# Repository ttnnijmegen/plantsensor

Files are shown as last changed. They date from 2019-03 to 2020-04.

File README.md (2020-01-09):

# plantsensor
indoor plant soil moisture sensor with temperature and humidity.
PCB based on HiGrow rev0.1 and RFM95
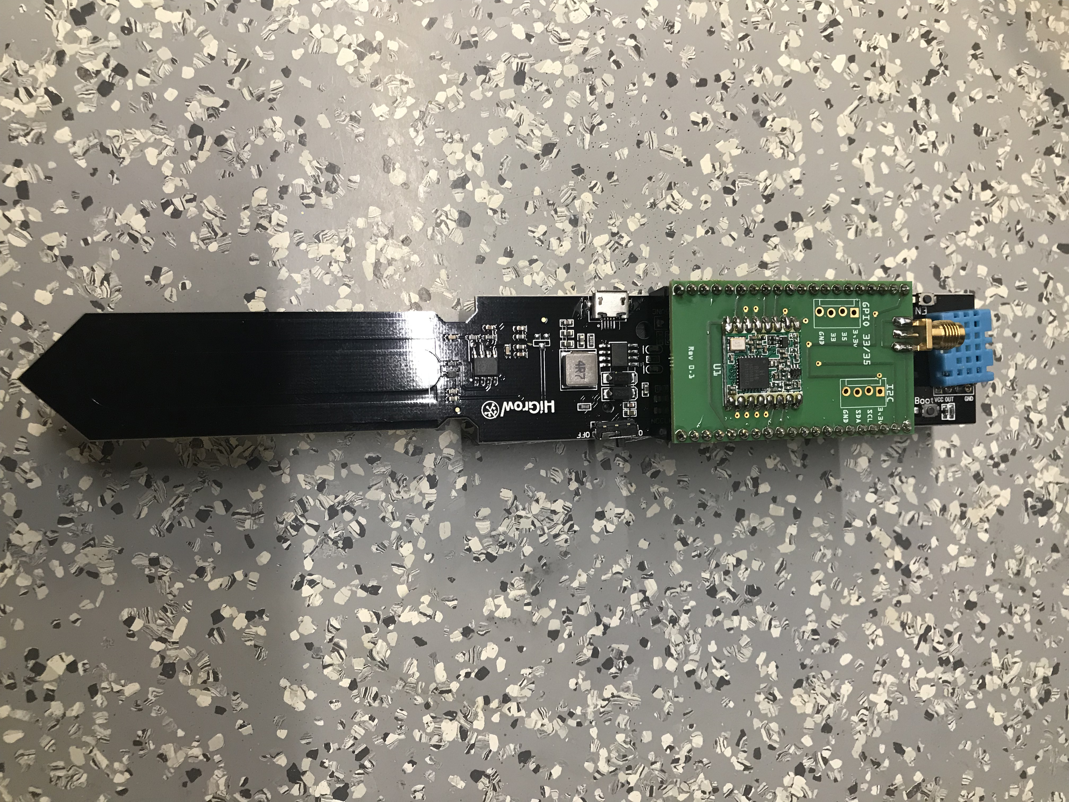
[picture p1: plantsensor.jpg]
plantsensor


Update: In the mean time there is a new product on the market. 
Apartently also with a LoRaWAN shield:
https://github.com/Xinyuan-LilyGO/TTGO-HiGrow
https://github.com/Xinyuan-LilyGO/LilyGO-T-HiGrow-LoRaWLAN

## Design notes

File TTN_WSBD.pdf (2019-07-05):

Workshop:
“Aan de slag met sensoren”

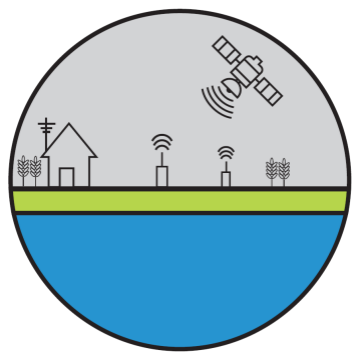
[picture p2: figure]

Workshop:
“Aan de slag met sensoren”

Amteburger kalibratie van
satellietbeelden met crowedsourced sensoren aangesloten op een crowedsourced netwerk

WIFI:
SSID: WSBD-Gast
WW: waterbeheer

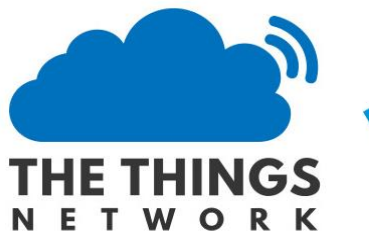
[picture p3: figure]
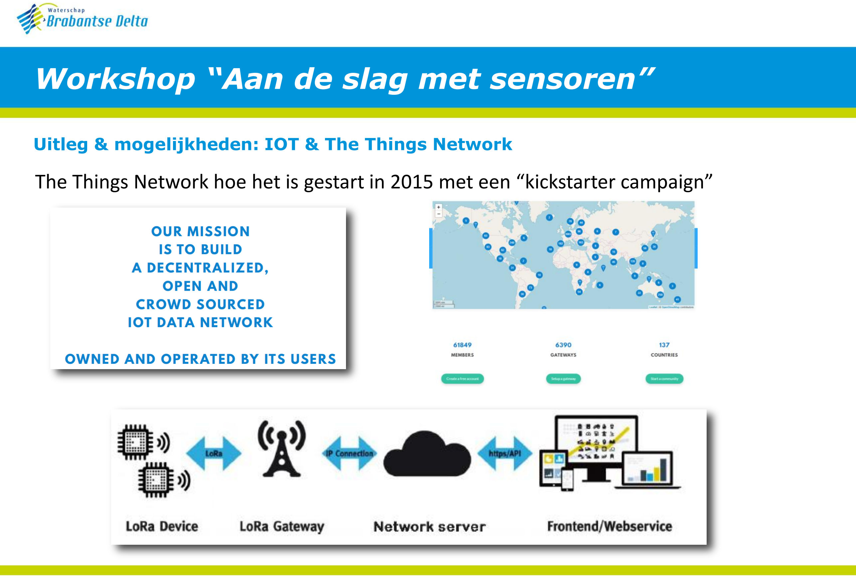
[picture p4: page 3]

Workshop “Aan de slag met sensoren”

Uitleg & mogelijkheden: IOT & The Things Network
The Things Network hoe het is gestart in 2015 met een “kickstarter campaign”

Workshop “Aan de slag met sensoren”

Uitleg & mogelijkheden: IOT & The Things Network
The Things Network hoe het is gestart in 2015 met een “kickstarter campaign”

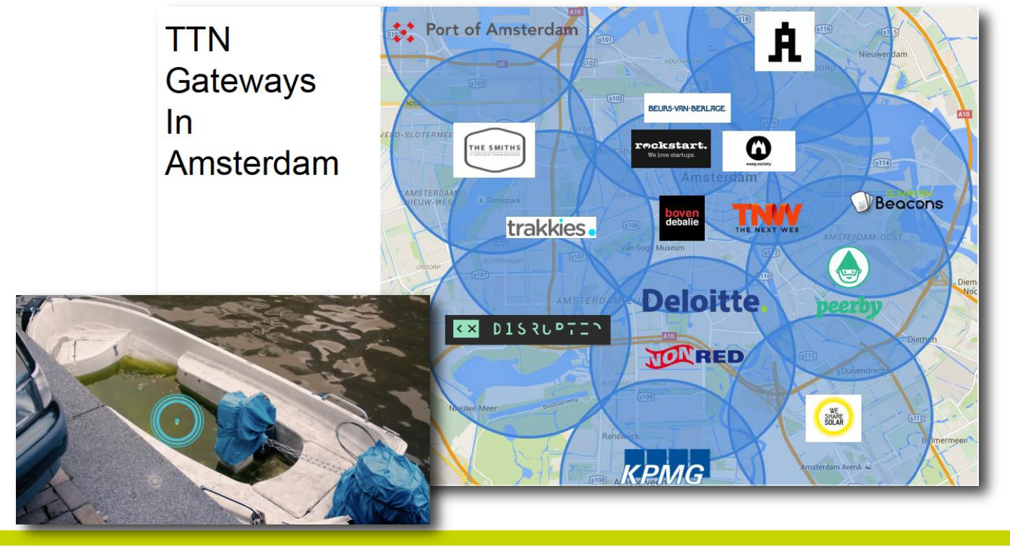
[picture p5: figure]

Workshop “Aan de slag met sensoren”

Uitleg & mogelijkheden: IOT & The Things Network

Internet of things

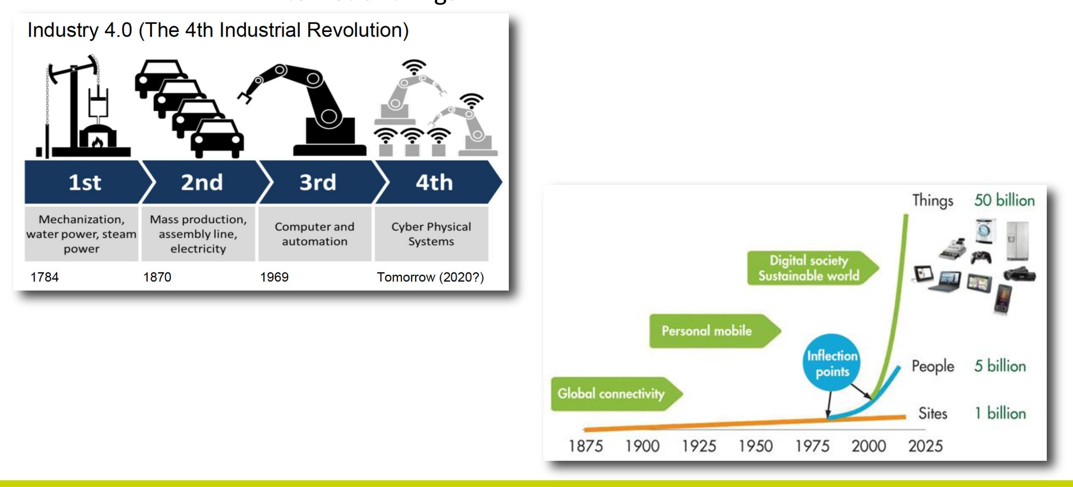
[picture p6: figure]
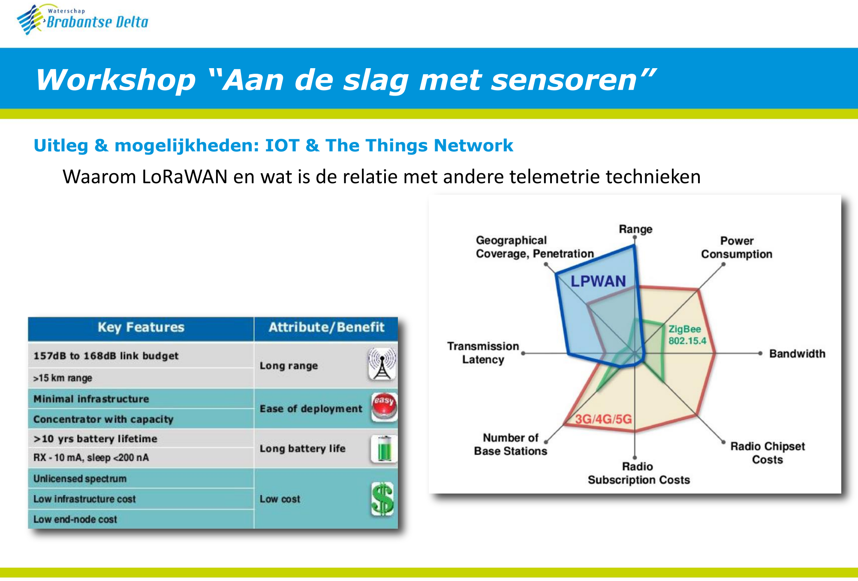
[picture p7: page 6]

Workshop “Aan de slag met sensoren”

Uitleg & mogelijkheden: IOT & The Things Network
Waarom LoRaWAN en wat is de relatie met andere telemetrie technieken

Workshop “Aan de slag met sensoren”

Uitleg & mogelijkheden: IOT & The Things Network
Waarom LoRaWAN en wat is de relatie met andere telemetrie technieken

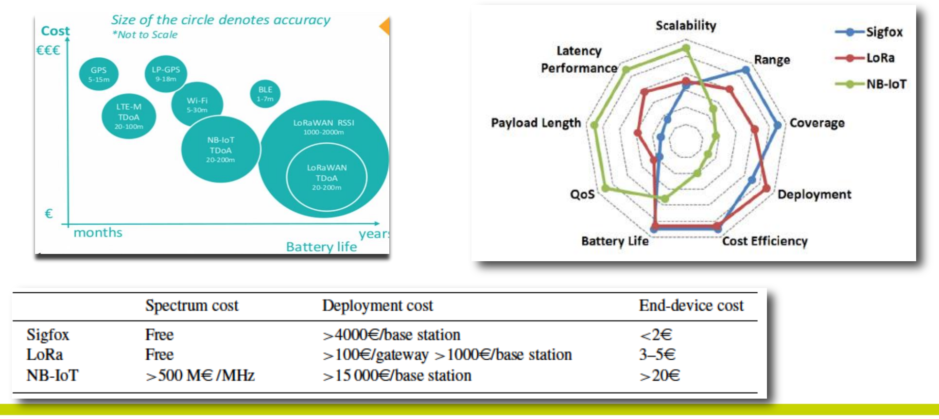
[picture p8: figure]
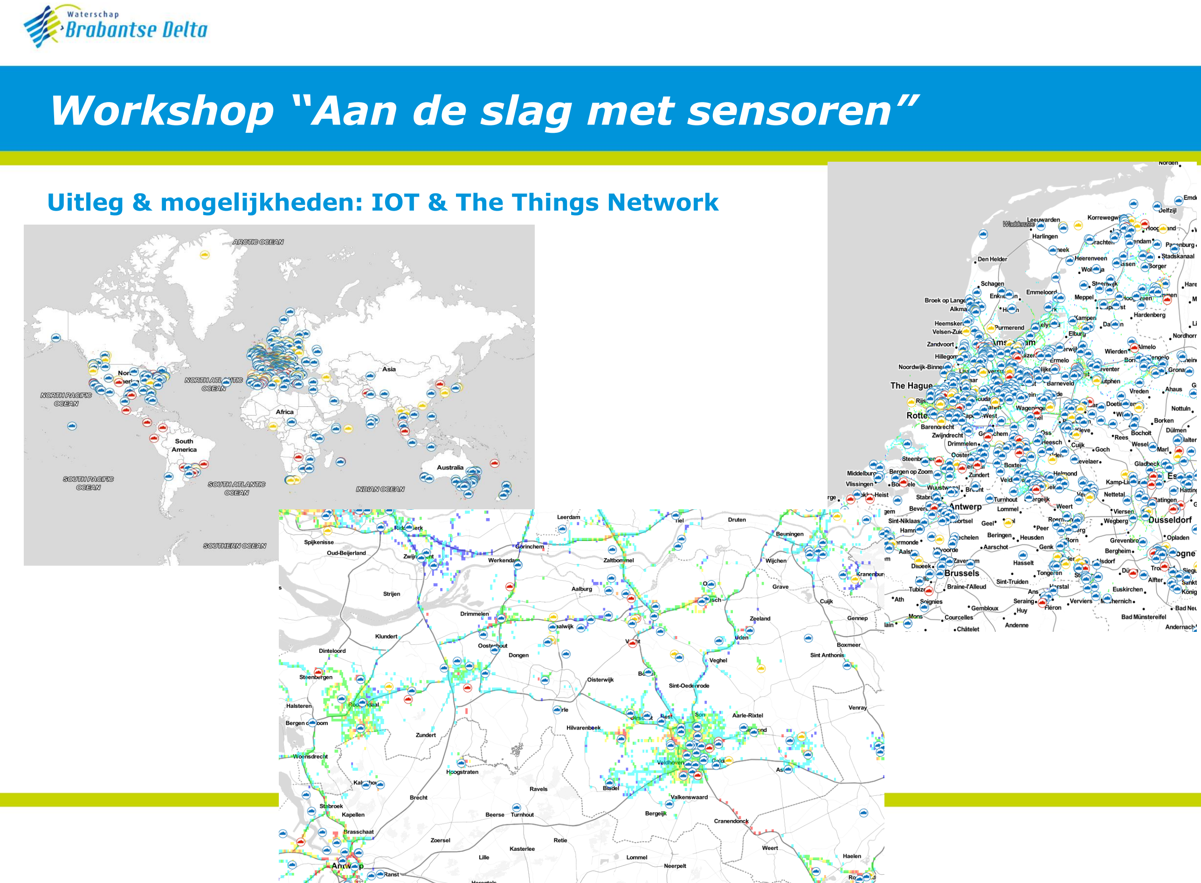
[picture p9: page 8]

Workshop “Aan de slag met sensoren”

Uitleg & mogelijkheden: IOT & The Things Network

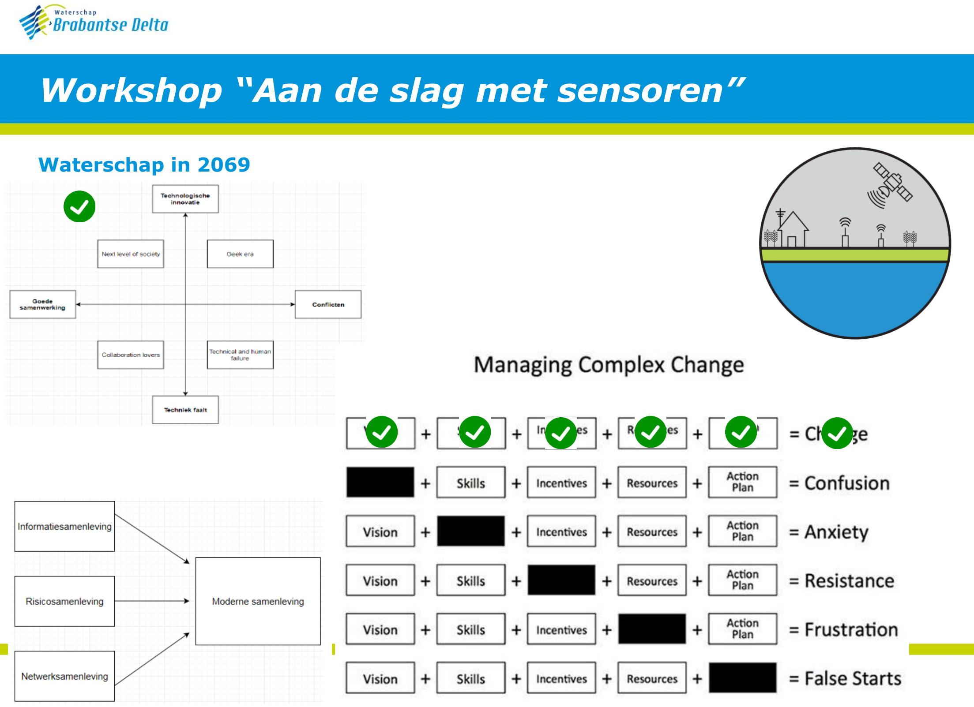
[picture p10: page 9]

Workshop “Aan de slag met sensoren”

Waterschap in 2069

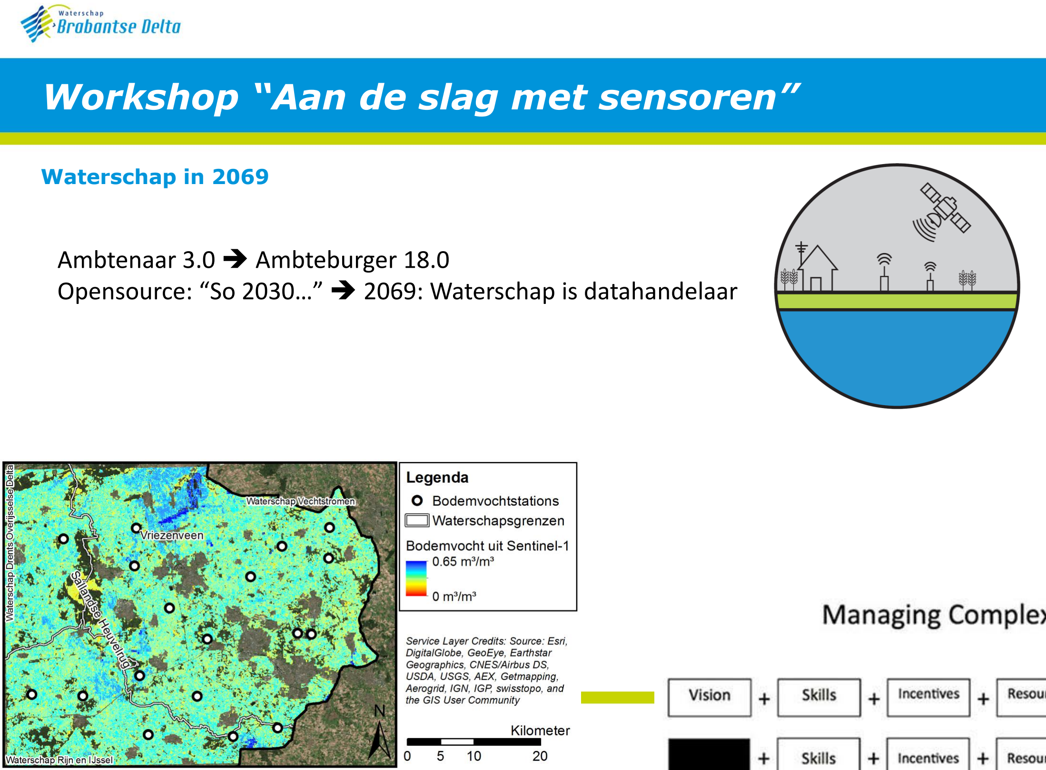
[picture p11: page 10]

Workshop “Aan de slag met sensoren”

Waterschap in 2069

Ambtenaar 3.0 → Ambteburger 18.0
Opensource: “So 2030…” → 2069: Waterschap is datahandelaar

Workshop “Aan de slag met sensoren”

Workshop intro

Hier nog plaatjes invoegen: Trello
Sensor
PCB
Casing

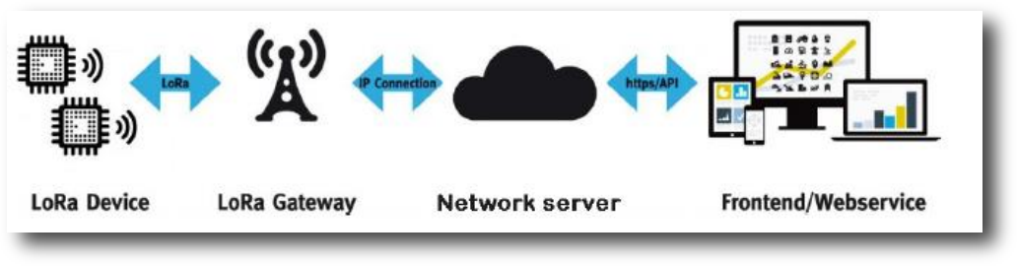
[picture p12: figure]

Workshop “Aan de slag met sensoren”

Inhoud

- 13:30-14:00
- Uitleg & mogelijkheden:
- IOT & The Things Network (mogelijkheden voor het waterschap)
- Waterschap 2069
- Workshop intro
- 14:00-15:00
- Workshop “Aan de slag met sensoren”
- 15:00-15:15
- Afsluiting – inspirerende ideeën

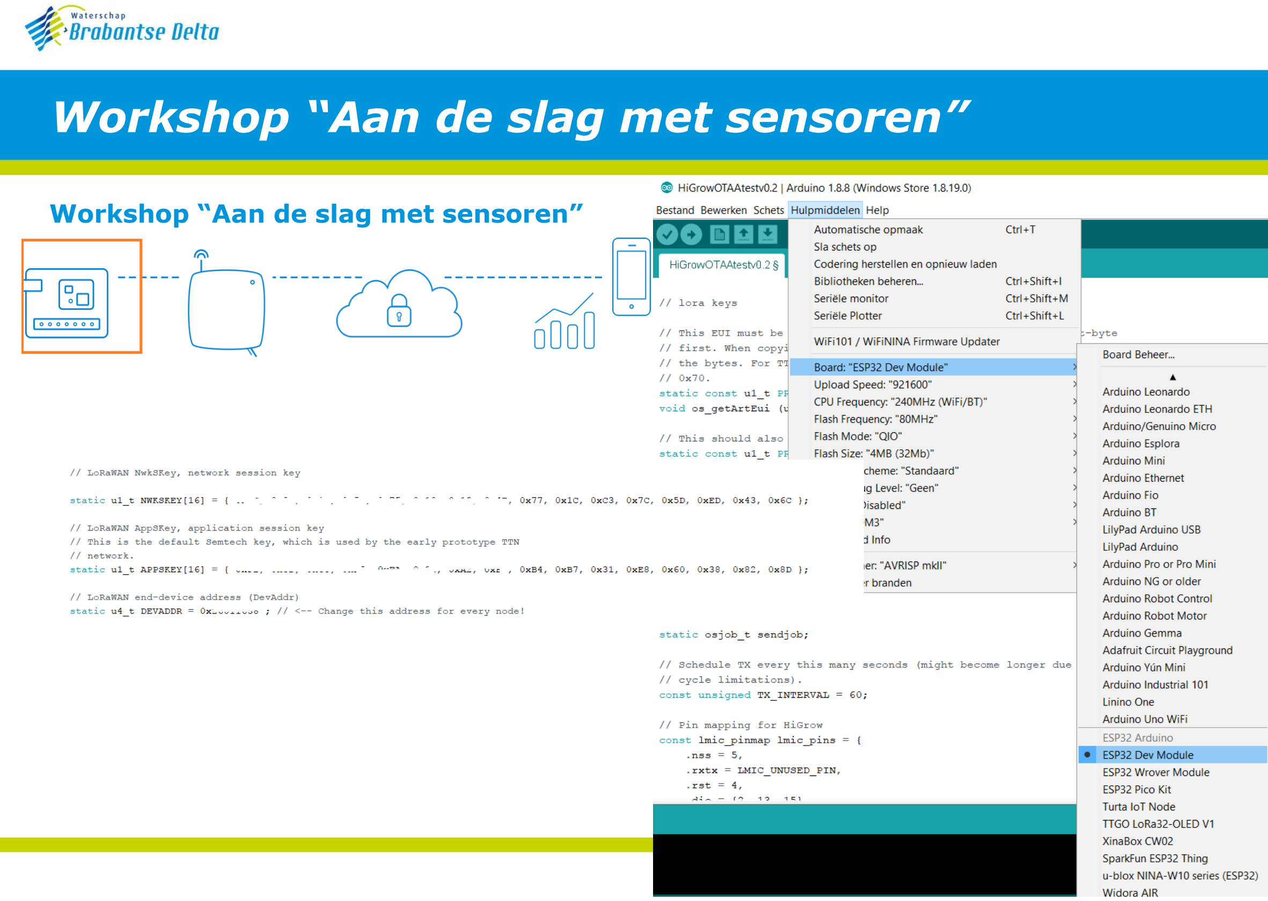
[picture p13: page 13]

Workshop “Aan de slag met sensoren”

Workshop “Aan de slag met sensoren”

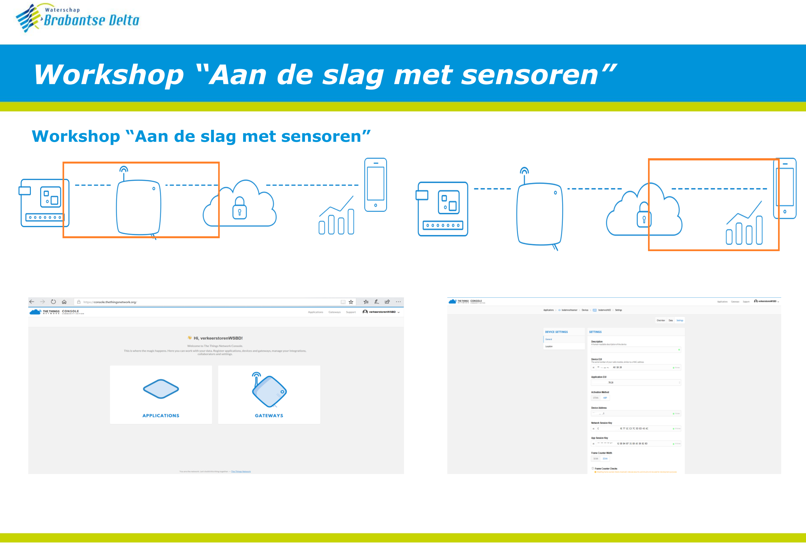
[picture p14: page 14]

Workshop “Aan de slag met sensoren”

Workshop “Aan de slag met sensoren”

Workshop “Aan de slag met sensoren”

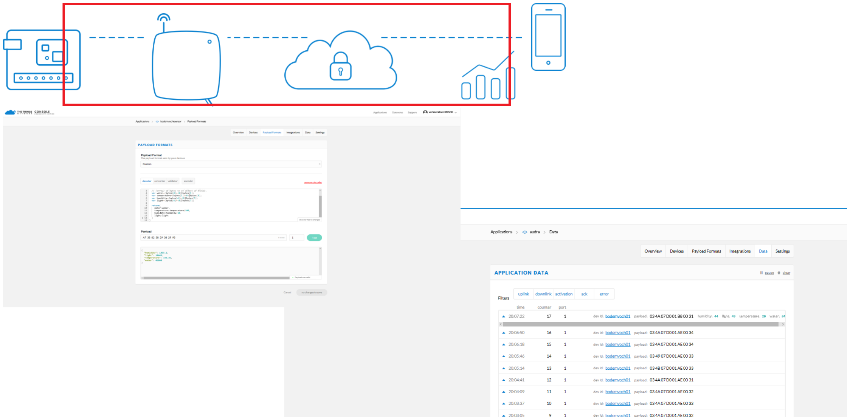
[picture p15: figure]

Workshop “Aan de slag met sensoren”

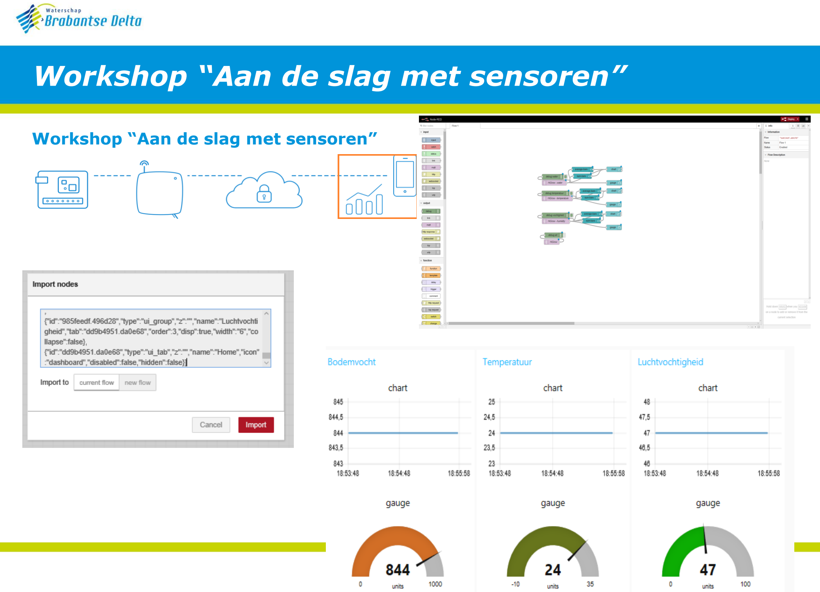
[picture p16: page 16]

Workshop “Aan de slag met sensoren”

Workshop “Aan de slag met sensoren”

Workshop “Aan de slag met sensoren”

Workshop “Aan de slag met sensoren”

Wellicht nog “nice to have” invoegen voor COLLOS

Workshop “Aan de slag met sensoren”

Inhoud

- 13:30-14:00
- Uitleg & mogelijkheden:
- IOT & The Things Network (mogelijkheden voor het waterschap)
- Waterschap 2069
- Workshop intro
- 14:00-15:00
- Workshop “Aan de slag met sensoren”
- 15:00-15:15
- Afsluiting – inspirerende ideeën

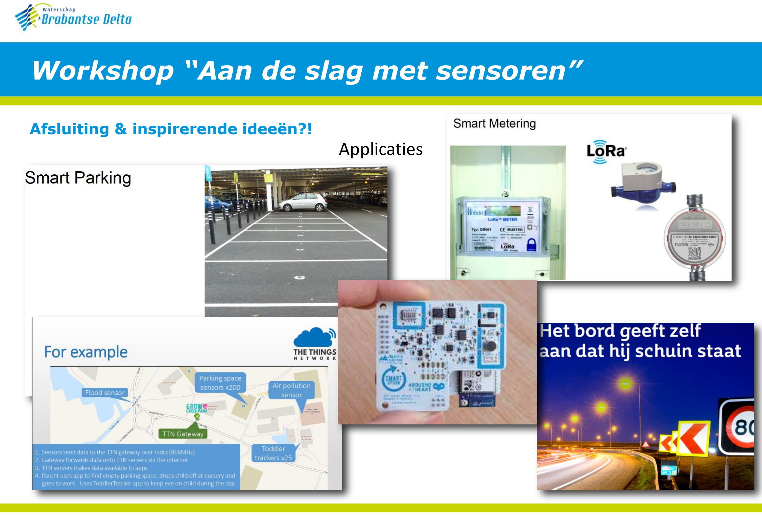
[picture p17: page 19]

Workshop “Aan de slag met sensoren”

Afsluiting & inspirerende ideeën?!
Applicaties

Workshop “Aan de slag met sensoren”

Credits

- Presentatie & ontwerp: | Roger & Wouter
- Ontwerp PCB: | Mark & Roger
- Code & debug: | Rob & Roger
- Installatie voorbereiding: Toine & Roger
- Infograph: | Mariozee
- Casing?: | Mark?
- Testers: | Wouter, Mark, Jarno, Linda, Rob,
| Audra , XXX

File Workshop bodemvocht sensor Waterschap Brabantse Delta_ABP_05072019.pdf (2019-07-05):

# Workshop bodemvocht sensor Waterschap Brabantse Delta v0.4_ABP

Dit is de uitgebreide handleiding ten behoeve van de workshop voor het maken van een sensor met een dashboard voor Waterschap Brabantse Delta. Hierbij wordt een microcontroller met diverse sensoren om de omgeving af te tasten aangesloten op “The Things Network” om middels LoRaWAN zend technologie gegevens te verzenden naar een eind applicatie. Dat is in deze workshop een node-red dashboard dat lokaal op de pc draait. De stappen die doorlopen worden betreffen de gehele architectuur van “The Things Network”. Onderstaande afbeelding visualiseert dit in een architectuur overzicht:

Dit overzicht zal ieder keer terug komen bij de relevante stappen in het proces van sensor naar eind applicatie. De stappen zijn onderstaand weergegeven in het overzicht van de inhoud.

## Inhoud

Data storage | Fout! Bladwijzer niet gedefinieerd.
IFTTT channel | Fout! Bladwijzer niet gedefinieerd.

## DEVICE: Opzet sensor

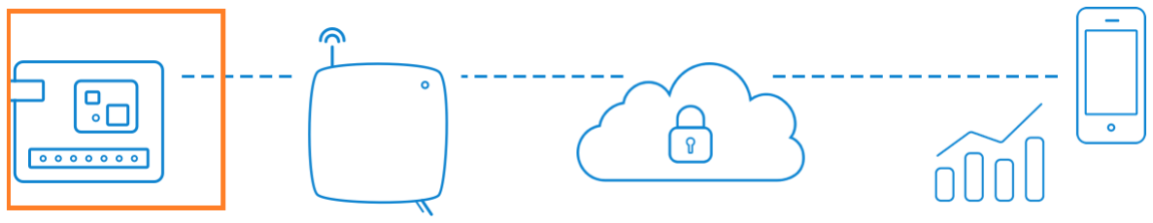
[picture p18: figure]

Allereerst dient het “device” te worden klaargemaakt om gegevens uit te lezen uit de sensoren die het heeft en deze in het juiste formaat door te zenden. Ieder “device” is uniek en bij dit “device” maken we gebruik van een microprocessor genaamd ESP32.

### Installatie arduino:

Download de arduino IDE (Integrated Development Environment) en installeer deze op uw computer.

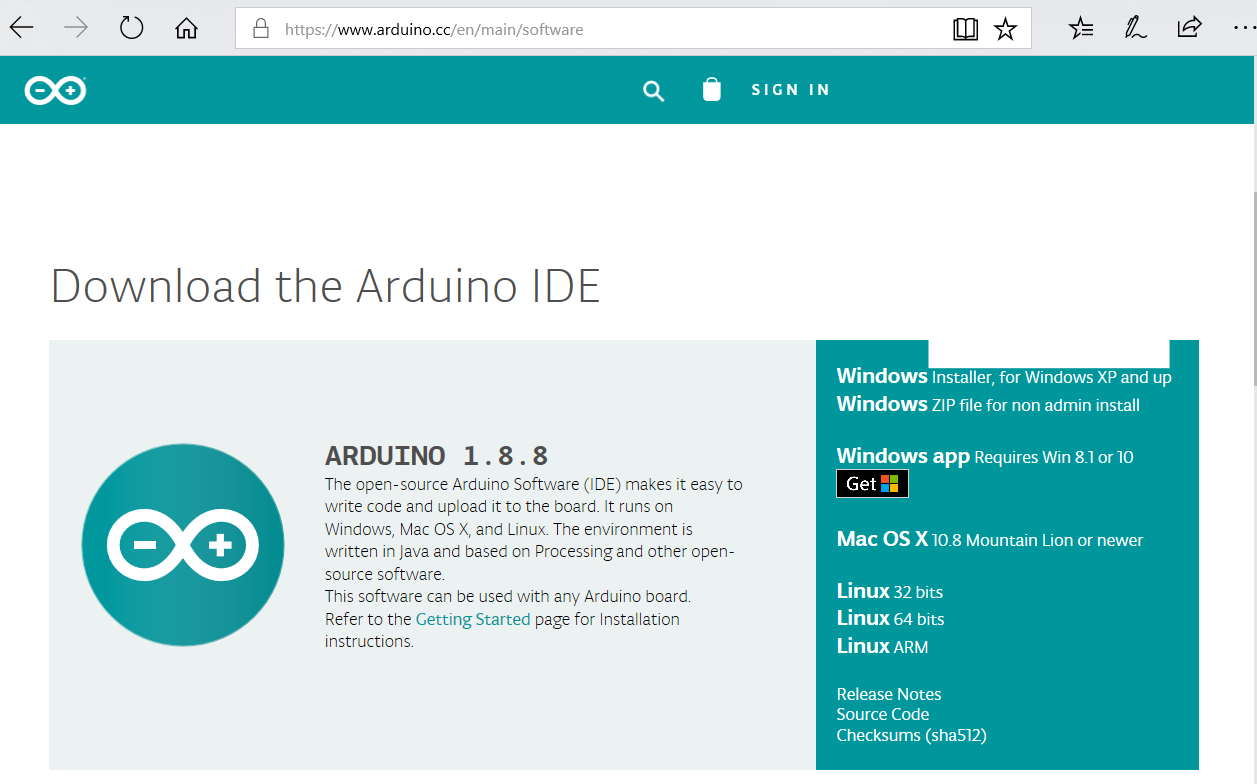
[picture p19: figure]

### Installatie ESP32 voor arduino

Om bepaalde type borden te kunnen gebruiken met de arduino IDE dienen deze te worden geïnstalleerd. Een uitgebreidere tutorial hierover voor de ESP32 is te vinden op de onderstaande link.

https://randomnerdtutorials.com/installing-the-esp32-board-in-arduino-ide-windows-instructions/

Kort samengevat komt het erop neer dat u bij voorkeuren de onderstaande link dient toe te voegen:

https://dl.espressif.com/dl/package_esp32_index.json

Ga vervolgens naar boardbeheer:

En installeer de ESP 32 borden:

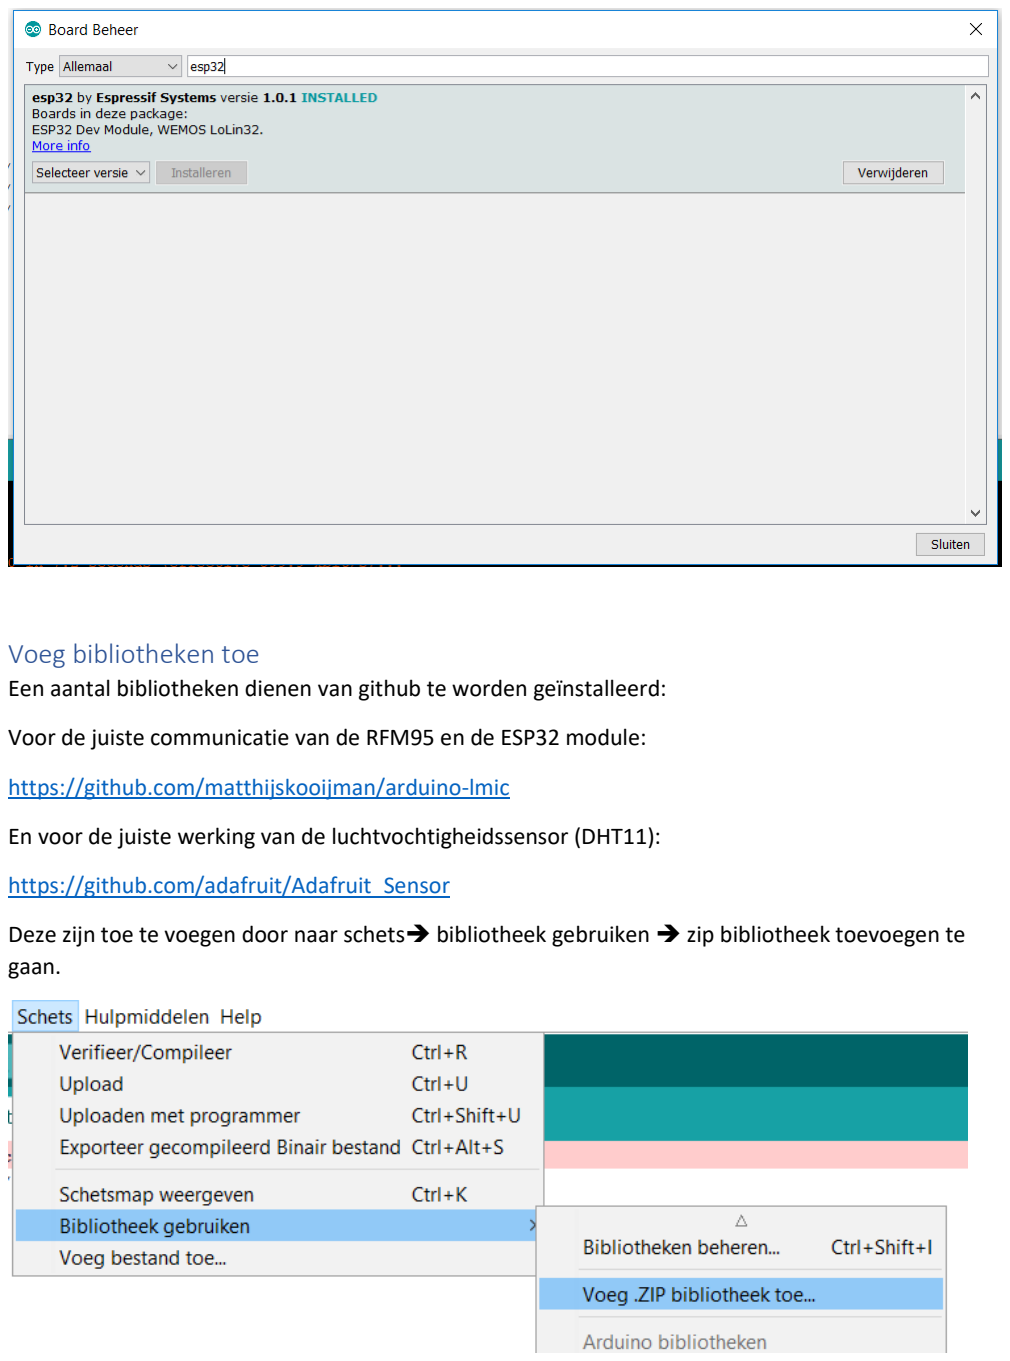
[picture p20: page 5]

### Voeg bibliotheken toe

Een aantal bibliotheken dienen van github te worden geïnstalleerd:

Voor de juiste communicatie van de RFM95 en de ESP32 module:

https://github.com/matthijskooijman/arduino-lmic

En voor de juiste werking van de luchtvochtigheidssensor (DHT11):

https://github.com/adafruit/Adafruit_Sensor

Deze zijn toe te voegen door naar schets→ bibliotheek gebruiken → zip bibliotheek toevoegen te gaan.

Daarnaast kunnen bibliotheken via de arduino IDE worden toegevoegd.

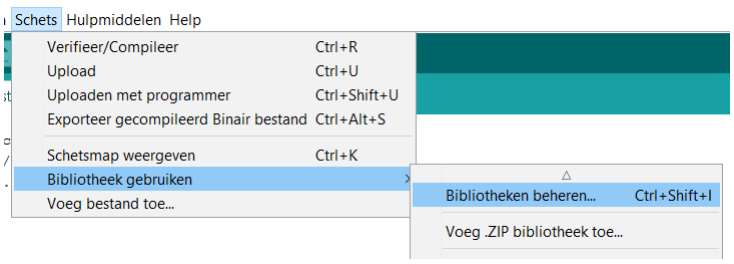
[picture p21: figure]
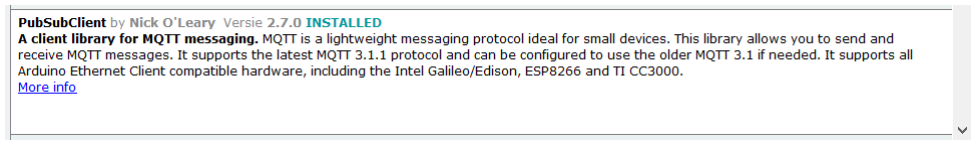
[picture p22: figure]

## CLOUD: Aanmaken van The Things Network account

Om gegevens te kunnen versturen, via de gateway, naar de cloud van “The things network” dient er een “The Things Network” account aangemaakt te worden.

Ga naar www.thethingsnetwork.org en “Sign up”.

Geef je credentials op en je zult een email ontvangen ten behoeve van verificatie van je email.

Log vervolgens in op: https://account.thethingsnetwork.org/users/login

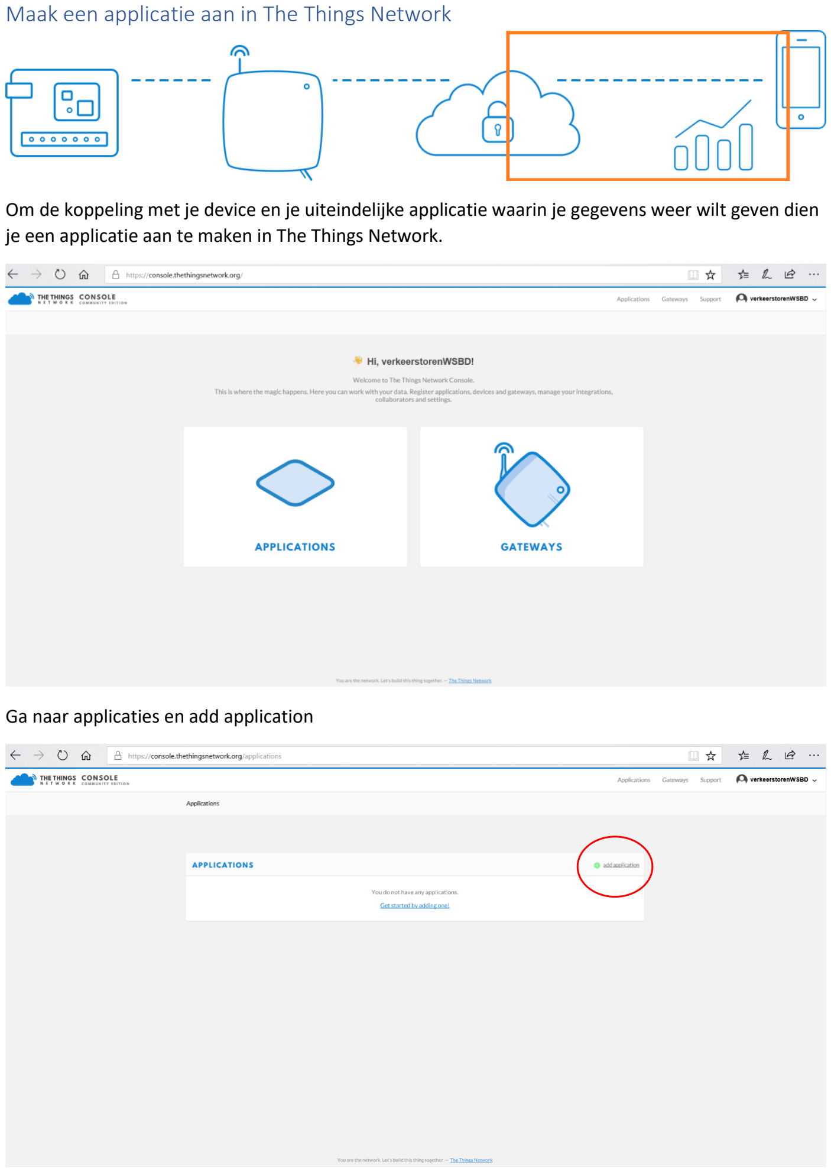
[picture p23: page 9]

### Maak een applicatie aan in The Things Network

Om de koppeling met je device en je uiteindelijke applicatie waarin je gegevens weer wilt geven dien je een applicatie aan te maken in The Things Network.

Ga naar applicaties en add application

Geef een applicatie ID op (in kleine letters zonder rare tekens) En “add application” (bijvoorbeeld bodemvochtsensor). Deze naam is uniek voor het gehele “The Things Network”.

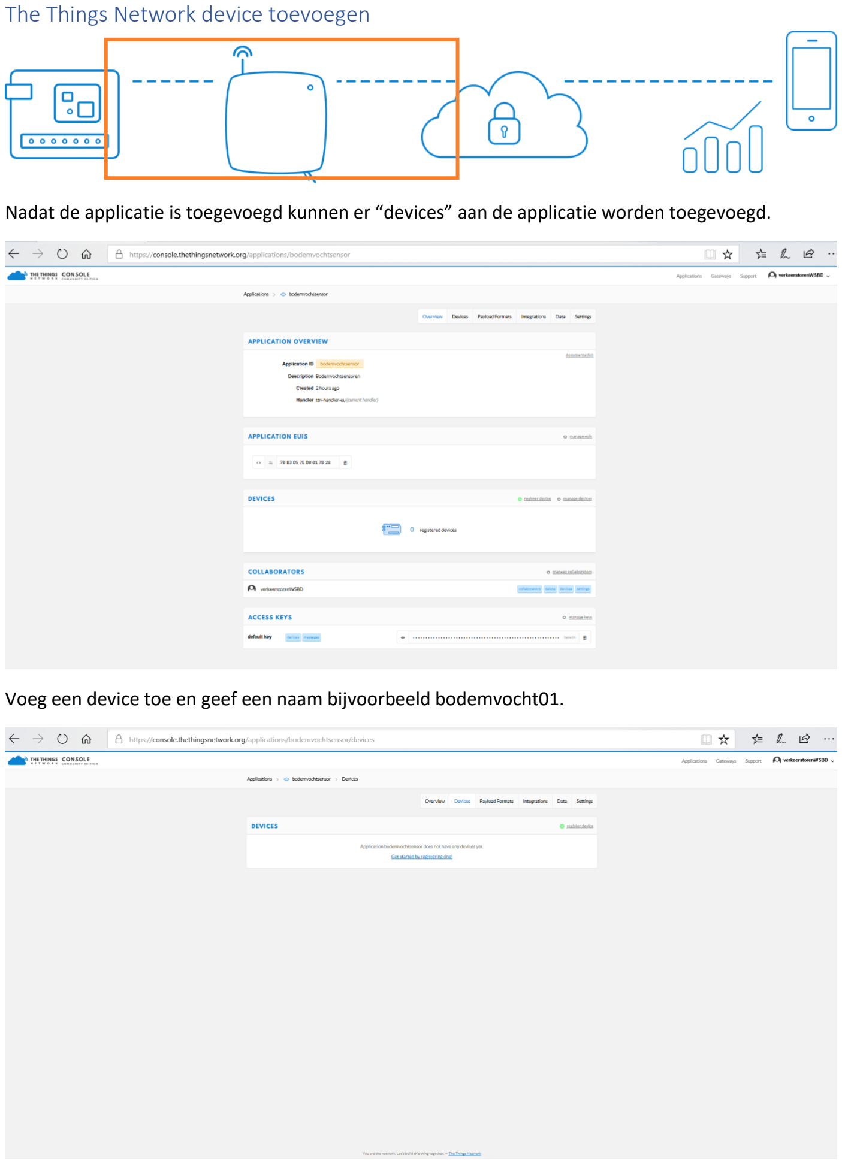
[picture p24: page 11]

### The Things Network device toevoegen

Nadat de applicatie is toegevoegd kunnen er “devices” aan de applicatie worden toegevoegd.

Voeg een device toe en geef een naam bijvoorbeeld bodemvocht01.

Laat Device EUI leeg om automatisch ingevuld te laten worden.

Druk bij device eui op de gekruisde pijltjes zodat device eui wordt gecreeerd

Je gaat nu terug naar het console en krijgt details van het net geregistreerde device te zien.

### ABP voorbeeld instellen in The Things Network

Ga naar settings en zet het device activation method op ABP in plaats van op OTAA. Zet daarnaast de framecounter check uit.

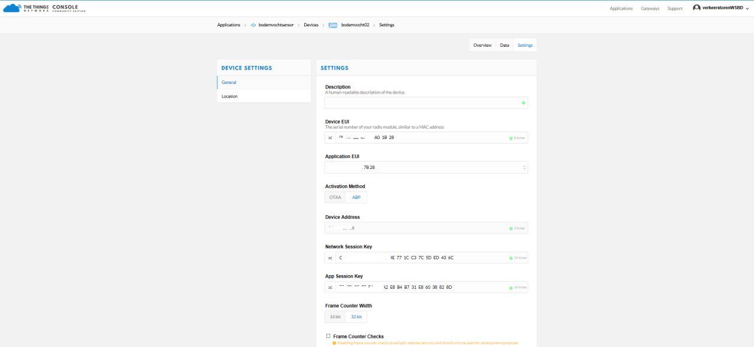
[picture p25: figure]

Zet framecounter check uit en klik vervolgens op de knop ‘save’.

### Arduino LoRa ABP sketch

De code voor de arduino sketch staat op:

https://github.com/ttnnijmegen/plantsensor/tree/master/src

Vul de sleutels in die bij de ABP device settings staan in the things network bij overview. Klik daarbij voor networksession key en app session key op <> zodat de sleutels in MSB formaat verschijnen.

Vul het device adress in achter 0x

De sketch is nu bijna klaar om te uploaden.

Na het invullen van de LoRA keys kan de sketch worden geverifieerd waarbij de code wordt gecompileerd en gecheckt op consistentie en aansluiting op het juiste board. Dit gebeurd met het vinkje. (bord is ESPDEV module)

Als dit allemaal goed is gegaan dient de com poort gecheckt te worden als het apparaat aan is gesloten op de USB poort:

Nu kan de sketch worden ge-upload naar het bord. Dit gebeurd met het pijltje naar rechts.

Bij het verbinden dient op de reset knop te worden gedrukt zodat de sketch naar het board kan uploaden. (connecting)


### Payload encryption


Om de juiste waarden in de applicatie te kunnen tonen dienen de bytes die worden verstuurd door de “device vertaald te worden in wat meer menselijke taal. Hiervoor is de payload functie. Ook worden gegevens hiermee versleuteld zodat alleen de gebruiker weet wat voor informatie het “device “ verstuurd. De decoder functie is toe te voegen door naar het payload format te gaan op de application pagina. Hier kan worden gekozen voor custom payload zoals in de ino file staat beschreven. Er kan ook worden gekozen voor het cayenne LPP formaat. Ook hiervoor dient de ino file te worden aangepast.

Knip en plak de payload decoder (in je applicatie bij payload formats) deze staat als tekst in het ino bestand op github:

https://github.com/ttnnijmegen/plantsensor/tree/master/src


selecteer het payload formaat dat correspondeerd met de ino file. Dus kopieer de tekst uit het ino bestand en selecteer custom om vervolgens deze tekst te plakken of selecteer het LPP formaat.

En test de functie met de volgende payload en druk op save

40 D1 1B 12 68 00 B0 00 01 DD C1 F2 E2 82 F2 03 97 7C 9F 49 B9

In het tabblad data zie je nu waarden in plaats van hex waarden verschijnen

## APPLICATION: Applicatie set-up

### Node-red dashboard installatie


Voor dit type dashboard is de custom payload optie vereist.

Node-red is een soort ETL (extract transfer load) tool voor diverse toepassingen. In deze workshop maken we gebruik van node-red om een simpel dashboard te maken van de data die “The things network” verstuurd middels MQTT.

Installatie van Node-red:

https://nodered.org/docs/getting-started/installation

Installeer eerst Node-js


Ga vervolgens verder met node-red door de volgende code in het opdrachtprompt te zetten (zoek CMD)

npm install -g --unsafe-perm node-red

Na een succesvolle installatie kan in het command prompt “node-red” worden ingevoerd en zo start node-red:


### Node-red gebruik

Nadat node-red in het command prompt is ingevoerd kan de node-red server worden benaderd op het adres dat door de server in het command prompt wordt opgegeven.

Dit is het lokale adres (127.0.0.1) met de poort 1880

Als dit ingevoerd is in een willekeurige internet browser start het gebruikersscherm van node-red:

Aan de linker kant staan diverse nodes die te gebruiken zijn aan de rechterkant het control panel en in het midden is “where the magic happens”…

Door naar de drie horizontale streepjes rechts boven te gaan opent een menu. Hier kun je “manage pallete” kiezen en op deze manier nieuwe nodes installeren.


Je ziet welke nodes er al zijn geïnstalleerd. En door op het tablad install te klikken kun je additionele nodes installeren.

Binnen deze workshop maken we gebruik van een Node-red dashboard en hiervoor dienen een aantal dashboard nodes geïnstalleerd te zijn. Namelijk:

*average-bars

*sum-bars

En “node-red-dashboard”


Nadat deze zijn geinstalleerd kan het voorontworpen dashboard worden geïmporteerd door simpelweg de code uit het “node-red.txt” document te kopieerden en te plakken.

De flows zijn nu te zien met de “dashboard nodes”

De opbouw van het dashboard is te zien als op de grafiek knop aan de rechterkant wordt gedrukt:

Door op het pijltje met het vierkantje te drukken wordt het scherm geopend waarop het dashboard wordt weergegeven.


Om het dashboard te voeden met waarden van de sensor dienen de juiste sleutels van de applicatie te worden ingevoerd in het dashboard.

Open een van de paarse nodes (MQTT nodes)

Vervang waar nu bodemvochtsensor staat door je eigen application ID en vervang bodemvocht02 door je eigen Device ID.


Klik daarna op het pennetje naast “eu.thethings.network:1883”. Druk op tabblad security

De gebruiksnaam vertaald zich in application ID

Het wachtwoord betreffen de acces keys van de applicatie

Klik op done in node red en op deploy om de applicatie te verversen

In het debug window (knopje met het lieve heersbeestje) zie je de waarden binnenkomen die de (groene) debug nodes ontvangen:


Wat uiteindelijk resulteert in waarden in het dashboard.

### Cayenne-COLLOS dashboard

Voor implementatie van Cayenne met het COLLOS dashboard dienen in de ino file te vinden op

https://github.com/ttnnijmegen/plantsensor/tree/master/src

de juiste regels te zijn gecommend en uncommend. Daarnaast dient bij de applications pagina het payload format “cayenne LPP” te zijn geselecteerd.


Bij de applications pagina, integrations voeg de cayenne integratie toe:

Vul daarbij een process ID in naar keuze:

Bij access keys selecteer de default keys.

Voeg ook de integratie “COLLOS” toe. Dit staat voor collaboration location services. Hiermee kan de locatie van de node bepaald worden.

Kies voor Process ID vul rssi in, bij access keys de default keys.

Bij url vul: https://api.preview.collos.org/semtech-localization-algorithms/v1/rssi

Method is POST, Cayenne channel is 20.

Voor de COLLOS subscription keys vul de sleutels in die je bij COLLOS hebt gekregen of apart hebt ontvangen.


Indien goed ingevuld zou de locatie van de device in overview zichtbaar moeten worden:

Er kan nu ook een dashboard worden gecreëerd op cayenne.


Door naar MyDevicesCayenne (https://cayenne.mydevices.com/?_ga=2.65099950.1099267064.1552320718-1638656246.1552320718) te gaan kunt u inloggen of een account aanmaken.

Na inloggen kan er een nieuw device worden aangemaakt:

Selecteer daarbij eerst bij LoraWAN, The things network:

En kies vervolgens het Cayenne protocol door cayenne in de zoekbalk in te typen;

Door de juiste device id in te voeren worden alle kanalen waarop de sensor waarden verzend vanzelf zichtbaar in het dashboard:

## Meer cloud functionaliteiten


### Collaboration

Het is mogelijk collaborators toe te voegen aan je applicatie. Hierdoor kun je samenwerken met elkaar en de data die binnenkomt van de sensoren in de applicatie met elkaar delen.

### COLLOS

ref: https://www.thethingsnetwork.org/docs/applications/collos/quick-start.html

This guide walks you through applying for Collos membership, subscribing to the APIs and configuring the Collos integration in The Things Network Console.

- Apply for a Collos membership: http://preview.collos.org/Home/Apply
- When your membership has been approved, sign in to the Collos portal
- Go to Products
- Click Semtech LoRaWAN Localization
- Click Subscribe to subscribe to the APIs
- Getting your subscription key
- Once your subscription has been approved, you can find your Collos subscription key.
- Sign in to the Collos portal
- Click on your name in the top right
- Click Profile
- Click Show to show your Collos subscription keys

- You can use both Primary key and Secondary key for the Collos integration.
- Configuring the integration
- Sign in to The Things Network Console
- Under Applications, go to your application
- Go to Integrations
- Click add integration
- Enter a Process ID, for example rssi or tdoa
- Select an Access Key. This key should have at least the devices rights to update the location in the device registry
- In URL, enter one of the Collos API endpoints:
- LoRa TDOA + WiFi: Copy https://api.preview.collos.org/localization-lora-recipes/v1/loraWifi
- LoRa TDOA: Copy https://api.preview.collos.org/semtech-localization-algorithms/v1/tdoa
- LoRa RSSI: Copy https://api.preview.collos.org/semtech-localization-algorithms/v1/rssi
- Enter your Collos subscription key
- Enter the Cayenne channel. If provided, the integration will send the location of your devices to myDevices Cayenne as GPS on the specified channel
- Click Add integration
- To compare results from the different algorithms, you can add multiple integration processes for the three algorithms available and use different Cayenne channels.


🎉 You have now successfully configured the Collos integration. You will now see your device moving in The Things Network Console as well as in myDevices Cayenne.

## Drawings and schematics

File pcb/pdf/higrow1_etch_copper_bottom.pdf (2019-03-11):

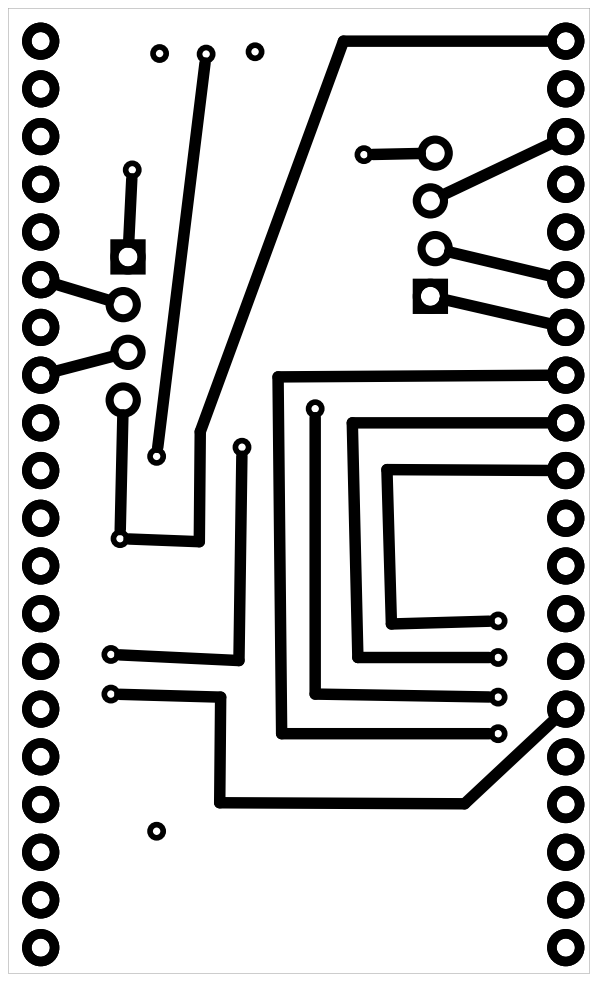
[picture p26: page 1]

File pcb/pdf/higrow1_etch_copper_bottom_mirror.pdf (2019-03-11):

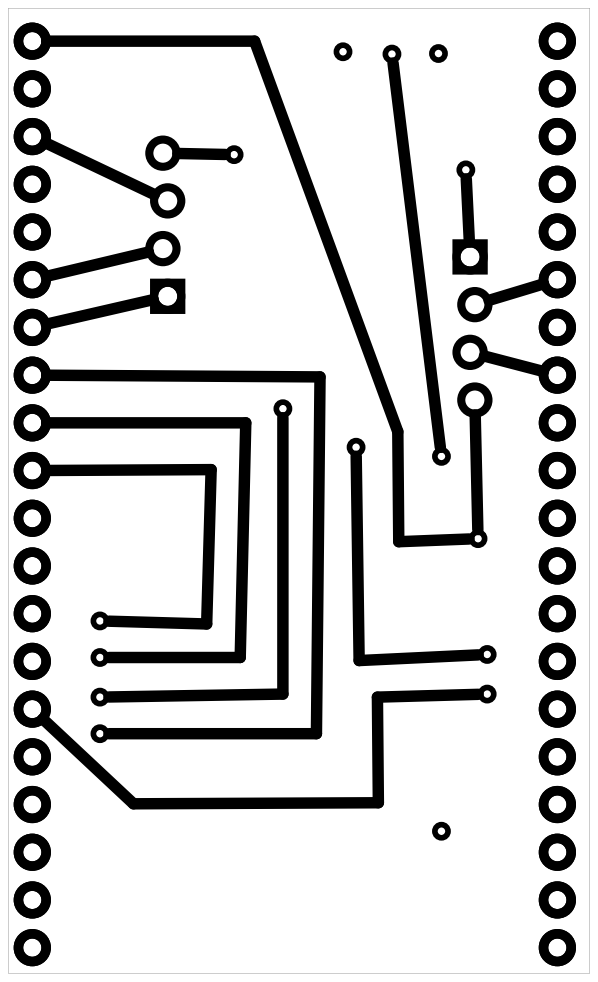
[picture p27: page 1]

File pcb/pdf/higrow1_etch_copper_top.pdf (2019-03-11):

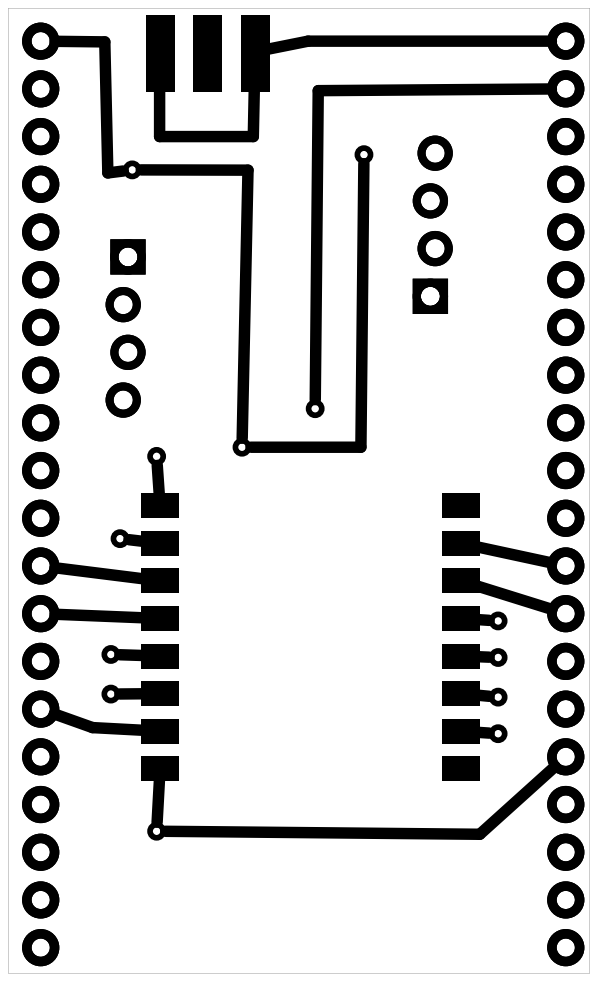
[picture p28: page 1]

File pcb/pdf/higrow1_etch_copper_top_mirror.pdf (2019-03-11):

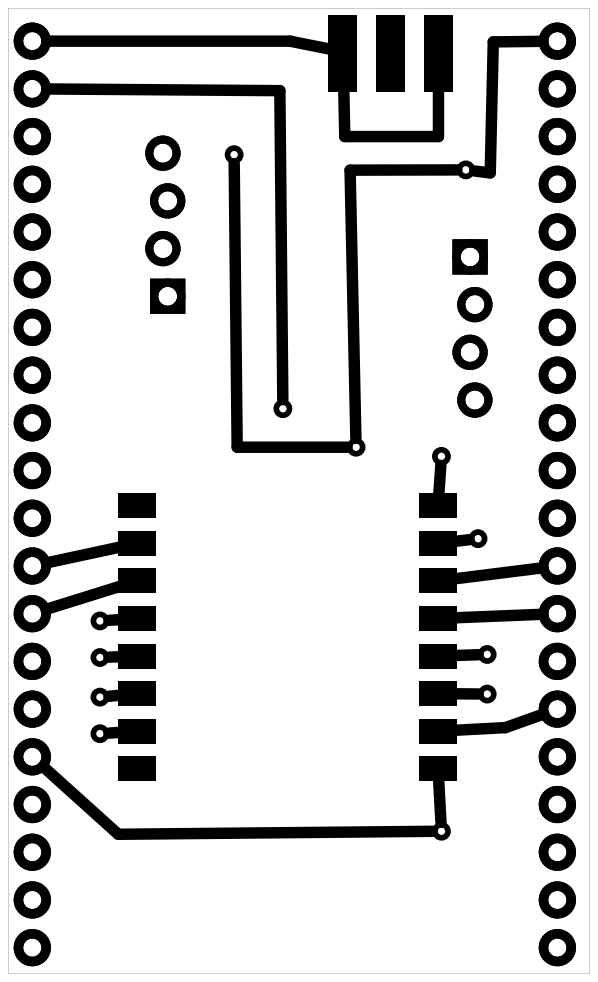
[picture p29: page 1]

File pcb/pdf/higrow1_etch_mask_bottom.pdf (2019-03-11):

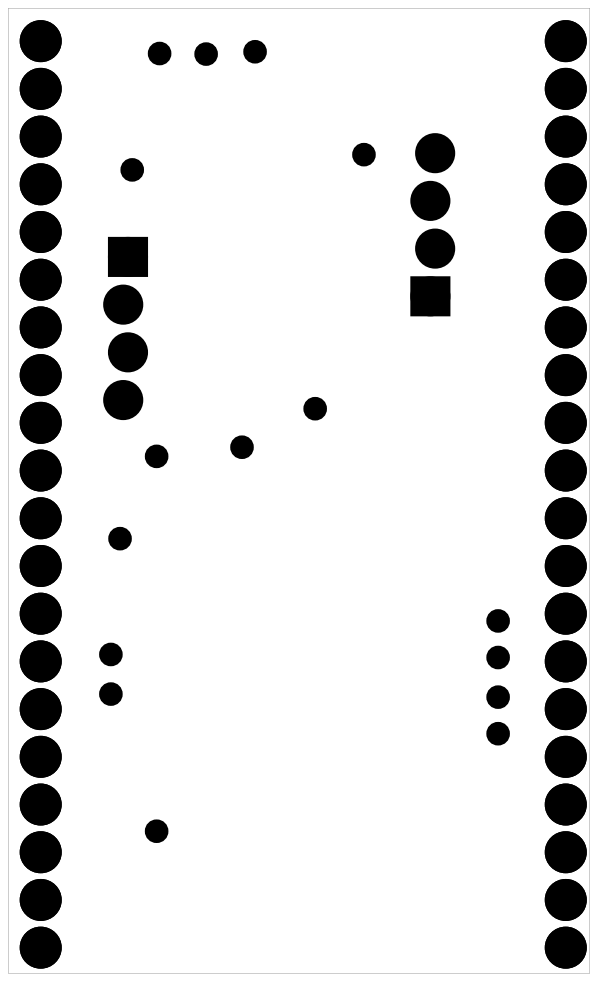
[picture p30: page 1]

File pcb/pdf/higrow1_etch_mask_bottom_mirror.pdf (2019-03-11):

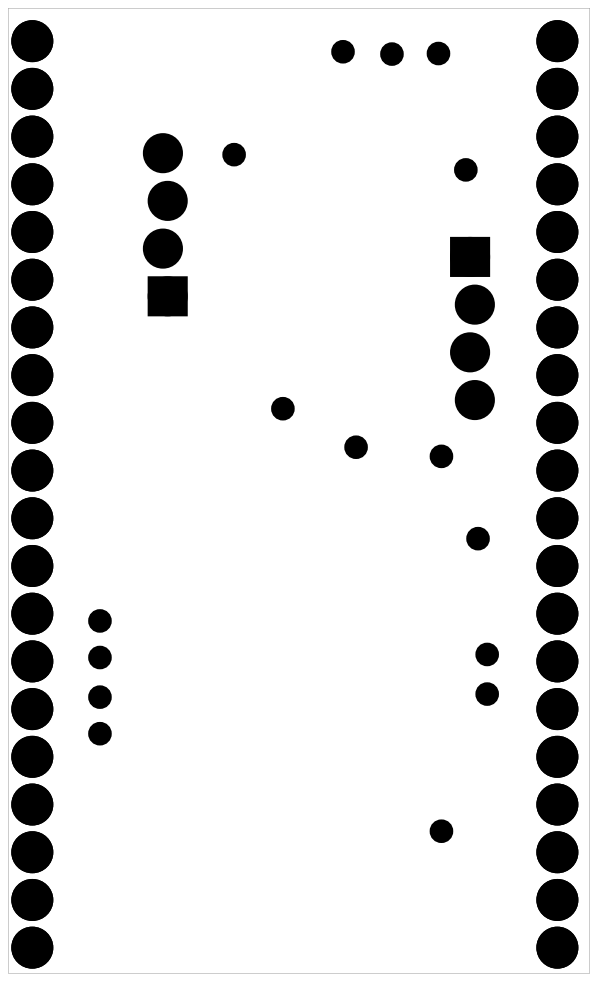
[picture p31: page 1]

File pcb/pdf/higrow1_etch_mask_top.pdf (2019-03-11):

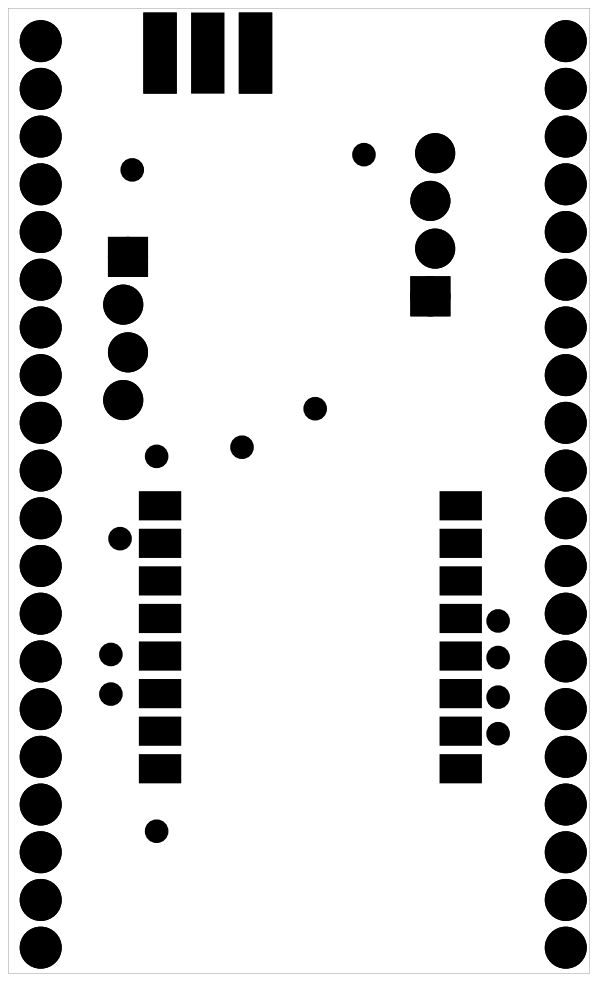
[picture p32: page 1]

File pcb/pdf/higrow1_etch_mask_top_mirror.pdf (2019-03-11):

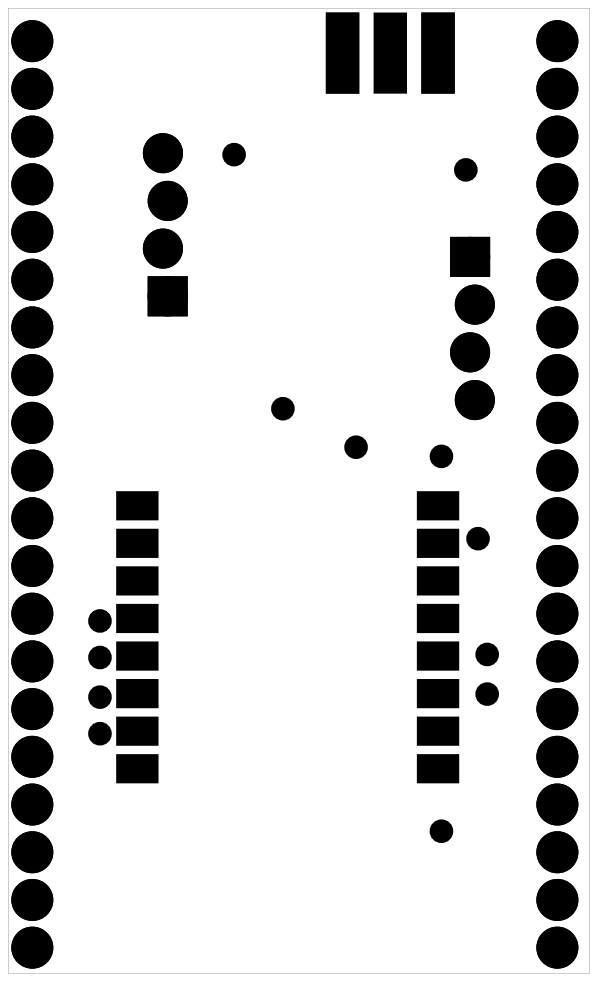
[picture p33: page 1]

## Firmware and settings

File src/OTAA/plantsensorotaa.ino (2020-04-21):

/*******************************************************************************
 * Copyright (c) 2015 Thomas Telkamp and Matthijs Kooijman
 * 
 * Copyright (c) 2018 Roger Meijs LoRaWAN implementation of the ESP32 "HiGrow" soil moisture, temperature and humidity sensor. 
 *
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
 * This example sends a valid LoRaWAN packet with payload "Hello,
 * world!", using frequency and encryption settings matching those of
 * the The Things Network.
 *
 * This uses OTAA (Over-the-air activation), where where a DevEUI and
 * application key is configured, which are used in an over-the-air
 * activation procedure where a DevAddr and session keys are
 * assigned/generated for use with all further communication.
 *
 * Note: LoRaWAN per sub-band duty-cycle limitation is enforced (1% in
 * g1, 0.1% in g2), but not the TTN fair usage policy (which is probably
 * violated by this sketch when left running for longer)!

 * To use this sketch, first register your application and device with
 * the things network, to set or generate an AppEUI, DevEUI and AppKey.
 * Multiple devices can use the same AppEUI, but each device has its own
 * DevEUI and AppKey.
 *
 * Do not forget to define the radio type correctly in config.h.
 * 
 *
 *******************************************************************************/

// to do 
//bluetooth en wifi off with lora ok
//WiFi.mode(WIFI_OFF); ok
//btStop(); ok
//turn leds off
//  Blue led does turn off (not blink) in the ESP32test


#include <lmic.h>
#include <hal/hal.h>
#include <SPI.h>
#include <WiFi.h>
#include <PubSubClient.h>
#include "esp_deep_sleep.h"
#include <DHT.h>                                  // DHT Sensor 
#include "user_config.h"                          // Fixed user configurable options
//#include <CayenneMQTTEthernet.h>                // Cayenne loopt vast ivm ethernet library?
#include <CayenneLPP.h>


// webserver
WiFiServer server(WEB_PORT);

/* create an instance of PubSubClient client */
WiFiClient espClient;
PubSubClient client(espClient);

// Initialize DHT sensor.
DHT dht(PIN_DHT, DHTTYPE);

#define LED_PIN 2

// on off switch of the buildin led
//int LED_BUILTIN = 2;



// ESP32 onboard temp board readout
#ifdef __cplusplus
extern "C" {
#endif
uint8_t temprature_sens_read();
#ifdef __cplusplus
}
#endif
uint8_t temprature_sens_read();



// Client variables 
long lastMsg = 0;


/////////////////////////////////////////////////////////////////////////
///////////////////////////////// lora keys/////////////////////////////

// This EUI must be in little-endian format (lsb), so least-significant-byte
// first. When copying an EUI from ttnctl output, this means to reverse
// the bytes. For TTN issued EUIs the last bytes should be 0xD5, 0xB3,
// 0x70.
static const u1_t PROGMEM APPEUI[8]={  };
void os_getArtEui (u1_t* buf) { memcpy_P(buf, APPEUI, 8);}

// This should also be in little endian format (lsb), see above.
static const u1_t PROGMEM DEVEUI[8]={ };
void os_getDevEui (u1_t* buf) { memcpy_P(buf, DEVEUI, 8);}

// This key should be in big endian format  (msb) (or, since it is not really a
// number but a block of memory, endianness does not really apply). In
// practice, a key taken from ttnctl can be copied as-is.
// The key shown here is the semtech default key.
static const u1_t PROGMEM APPKEY[16] = { };
void os_getDevKey (u1_t* buf) {  memcpy_P(buf, APPKEY, 16);}

//////////////////////////////////////////////////////////////////////////

static osjob_t sendjob;

// Schedule TX every this many seconds (might become longer due to duty
// cycle limitations).
const unsigned TX_INTERVAL = 60;

// Pin mapping for HiGrow
const lmic_pinmap lmic_pins = {
    .nss = 5,
    .rxtx = LMIC_UNUSED_PIN,
    .rst = 4,
    .dio = {2, 13, 15},
};

#define MAX_SIZE 200
CayenneLPP lpp(MAX_SIZE);

void onEvent (ev_t ev) {
    Serial.print(os_getTime());
    Serial.print(": ");
    switch(ev) {
        case EV_SCAN_TIMEOUT:
            Serial.println(F("EV_SCAN_TIMEOUT"));
            break;
        case EV_BEACON_FOUND:
            Serial.println(F("EV_BEACON_FOUND"));
            break;
        case EV_BEACON_MISSED:
            Serial.println(F("EV_BEACON_MISSED"));
            break;
        case EV_BEACON_TRACKED:
            Serial.println(F("EV_BEACON_TRACKED"));
            break;
        case EV_JOINING:
            Serial.println(F("EV_JOINING"));
            break;
        case EV_JOINED:
            Serial.println(F("EV_JOINED"));

            // Disable link check validation (automatically enabled
            // during join, but not supported by TTN at this time).
            LMIC_setLinkCheckMode(0);
            break;
        case EV_RFU1:
            Serial.println(F("EV_RFU1"));
            break;
        case EV_JOIN_FAILED:
            Serial.println(F("EV_JOIN_FAILED"));
            break;
        case EV_REJOIN_FAILED:
            Serial.println(F("EV_REJOIN_FAILED"));
            break;
            break;
        case EV_TXCOMPLETE:
            Serial.println(F("EV_TXCOMPLETE (includes waiting for RX windows)"));
            if (LMIC.txrxFlags & TXRX_ACK)
              Serial.println(F("Received ack"));
            if (LMIC.dataLen) {
              Serial.println(F("Received "));
              Serial.println(LMIC.dataLen);
              Serial.println(F(" bytes of payload"));
            }
            // Schedule next transmission
            os_setTimedCallback(&sendjob, os_getTime()+sec2osticks(TX_INTERVAL), do_send);
            break;
        case EV_LOST_TSYNC:
            Serial.println(F("EV_LOST_TSYNC"));
            break;
        case EV_RESET:
            Serial.println(F("EV_RESET"));
            break;
        case EV_RXCOMPLETE:
            // data received in ping slot
            Serial.println(F("EV_RXCOMPLETE"));
            break;
        case EV_LINK_DEAD:
            Serial.println(F("EV_LINK_DEAD"));
            break;
        case EV_LINK_ALIVE:
            Serial.println(F("EV_LINK_ALIVE"));
            break;
         default:
            Serial.println(F("Unknown event"));
            break;
    }
}

void do_send(osjob_t* j){
    // Check if there is not a current TX/RX job running
    if (LMIC.opmode & OP_TXRXPEND) {
        Serial.println(F("OP_TXRXPEND, not sending"));
    } else {
        // Prepare upstream data transmission at the next possible time.
 //       byte payload[8];
        // lowpower protocol reset
        lpp.reset();

        // get values ready
        uint8_t water = getWater();
        uint8_t temp = getTemperature();
        uint8_t hum = getHumidity();
        uint8_t HallRead = hallRead();
        uint8_t BoardTemperature = (temprature_sens_read()- 32) / 1.8;

        // place them in LPP context
        lpp.addTemperature(0, temp);
        lpp.addRelativeHumidity(1, hum);
        lpp.addBarometricPressure(2, water);
        lpp.addAnalogOutput(3, HallRead);
        lpp.addTemperature(4, BoardTemperature);

        // send LPP data
        LMIC_setTxData2(1, lpp.getBuffer(), lpp.getSize(), 0);
        Serial.println(F("Packet queued"));   

// sending without LPP
//        uint16_t water = getWater();
//        uint16_t temperature = getTemperature()*100;
//        uint16_t humidity = getHumidity()*10;
//        uint16_t light = getLight();
//
//        payload[0] = highByte(water);
//        payload[1] = lowByte(water);
//        payload[2] = highByte(temperature);
//        payload[3] = lowByte(temperature);
//        payload[4] = highByte(humidity);
//        payload[5] = lowByte(humidity);
//        payload[6] = highByte(light);
//        payload[7] = lowByte(light);
//        
//        LMIC_setTxData2(1, payload, 8, 0);
//        Serial.println(F("Packet queued"));

    }
    // Next TX is scheduled after TX_COMPLETE event.
}

// Build JSON - not for sensding with LoRaWAN
String toJson(){
        char body[60];
        sprintf(body, "{\"water\":%d,\"hum\":%d,\"temp\":%d}",
                getWater(), getHumidity(), getTemperature());
 
  return body;
}

// Read the water level and return a readable value
int getWater() {
  int water = analogRead(PIN_SOIL);
  water = map(water, 0, 4095, 0, 1023);
  water = constrain(water, 0, 1023);
  return water;
}

// Read the light level and return a readable value
int getLight() {
  int light = analogRead(PIN_LIGHT);
  light = map(light, 0, 4095, 0, 1023);
  light = constrain(light, 0, 1023);
  return light;
}

// Read the temperature and return a readable value
int getTemperature() {
  return dht.readTemperature();
}
// Read ESP32 internal hall sensor
int HallSensor(){
Serial.println("hall sensor:");
Serial.println(hallRead());
return hallRead();
}
// Read the humidity level and return a readable value
int getHumidity() {
  return dht.readHumidity();
}

void setup() {
    Serial.begin(115200);
      dht.begin();                                    // initialize the DHT sensor
  // define blue light
    pinMode(LED_PIN, OUTPUT);
    digitalWrite (LED_PIN, LOW);
  
    Serial.println(F("Starting"));

    // LMIC init
    os_init();
    // Reset the MAC state. Session and pending data transfers will be discarded.
    LMIC_reset();

    #if defined(CFG_eu868)
    // Set up the channels used by the Things Network, which corresponds
    // to the defaults of most gateways. Without this, only three base
    // channels from the LoRaWAN specification are used, which certainly
    // works, so it is good for debugging, but can overload those
    // frequencies, so be sure to configure the full frequency range of
    // your network here (unless your network autoconfigures them).
    // Setting up channels should happen after LMIC_setSession, as that
    // configures the minimal channel set.
    // NA-US channels 0-71 are configured automatically
    LMIC_setupChannel(0, 868100000, DR_RANGE_MAP(DR_SF12, DR_SF7),  BAND_CENTI);      // g-band
    LMIC_setupChannel(1, 868300000, DR_RANGE_MAP(DR_SF12, DR_SF7B), BAND_CENTI);      // g-band
    LMIC_setupChannel(2, 868500000, DR_RANGE_MAP(DR_SF12, DR_SF7),  BAND_CENTI);      // g-band
    LMIC_setupChannel(3, 867100000, DR_RANGE_MAP(DR_SF12, DR_SF7),  BAND_CENTI);      // g-band
    LMIC_setupChannel(4, 867300000, DR_RANGE_MAP(DR_SF12, DR_SF7),  BAND_CENTI);      // g-band
    LMIC_setupChannel(5, 867500000, DR_RANGE_MAP(DR_SF12, DR_SF7),  BAND_CENTI);      // g-band
    LMIC_setupChannel(6, 867700000, DR_RANGE_MAP(DR_SF12, DR_SF7),  BAND_CENTI);      // g-band
    LMIC_setupChannel(7, 867900000, DR_RANGE_MAP(DR_SF12, DR_SF7),  BAND_CENTI);      // g-band
    LMIC_setupChannel(8, 868800000, DR_RANGE_MAP(DR_FSK,  DR_FSK),  BAND_MILLI);      // g2-band
    // TTN defines an additional channel at 869.525Mhz using SF9 for class B
    // devices' ping slots. LMIC does not have an easy way to define set this
    // frequency and support for class B is spotty and untested, so this
    // frequency is not configured here.
    #elif defined(CFG_us915)
    // NA-US channels 0-71 are configured automatically
    // but only one group of 8 should (a subband) should be active
    // TTN recommends the second sub band, 1 in a zero based count.
    // https://github.com/TheThingsNetwork/gateway-conf/blob/master/US-global_conf.json
    LMIC_selectSubBand(1);
    #endif

    // Disable link check validation
    LMIC_setLinkCheckMode(0);

    // TTN uses SF9 for its RX2 window.
    LMIC.dn2Dr = DR_SF9;

    // Set data rate and transmit power for uplink (note: txpow seems to be ignored by the library)
    LMIC_setDrTxpow(DR_SF7,14);

    // Start job (sending automatically starts OTAA too)
    do_send(&sendjob);

    #if (WEB_SERVER == 1)  
  // We start by connecting to a WiFi network
  Serial.println();
  Serial.println();
  Serial.print("Connecting to ");
  Serial.println(WIFI_SSID);
  
  WiFi.begin(WIFI_SSID, WIFI_PASS);               // Connect with Wifi
  
  while(WiFi.status() != WL_CONNECTED) {          // Try to create connection to WiFi
    delay(500);
    Serial.print(".");
  }
  Serial.println("WiFi connected");
  Serial.print("IP address: ");
  Serial.println(WiFi.localIP());
#elif (WEB_SERVER == 0)  
  WiFi.mode(WIFI_OFF);
  btStop();
  
#endif
  // Config pins
  pinMode(16, OUTPUT); 
  pinMode(PIN_POWER, INPUT);
  digitalWrite(16, LOW);  

  


  if (MQTT == 1) {                                // MQ Start
    client.setServer(MQTT_BROKER, MQTT_PORT);     // Configure the MQTT server
    Serial.println("");
    Serial.print("Set MQTT Broker: ");
    Serial.println(MQTT_BROKER);
    Serial.print("Set MQTT Port: ");
    Serial.println(MQTT_PORT);
  } else {                                        // MQ Stop
    Serial.println("");
    Serial.println("MQTT off");
  }

  if (WEB_SERVER == 1) {                          // Webserver Start
    server.begin();
    Serial.println("Webserver is online");
    Serial.println("Set Webserver Port to: ");
    Serial.println(WEB_PORT);
  } else {                                        // Webserver Stop
    Serial.println("");
    Serial.println("Webserver is offline");
    WiFi.mode(WIFI_OFF);
    Serial.println("WIFI is off (blue light should be out)");
    btStop();
    Serial.println("Bluetooth is off (blue light should be out)");
 }
 // if (CAYENNE_SUPPORT ==1) {                      // Cayenne start
 // Cayenne.begin(username, password, clientID);
}

void loop() {
  digitalWrite (LED_PIN, LOW);
    os_runloop_once();
    // -- MQTT --------------------------------------------
  if (MQTT == 1) {
    if (!client.connected()) {                    // Check the connection, if disconnected try to reconnect
      mqttconnect();
    }

    if (WEB_SERVER == 1) {                        // go to normal interval without deepsleep
      long now = millis();                        // count the seconds since the arduino board startet
      if (now - lastMsg > MQTT_INTERVAL*1000) {   
        lastMsg = now;

        char buf[1024];
        toJson().toCharArray(buf, 1024);          // json String to char Array
        client.publish(MQTT_TOPIC, buf);          // send the json to the mq
      }
    } else {
        char buf[1024];
        toJson().toCharArray(buf, 1024);          // json String to char Array
        client.publish(MQTT_TOPIC, buf);          // send the json to the mq
        delay(5);                                 // wait while sending the message
    }
  }



  // -- Web-Server -------------------------------------
  if (WEB_SERVER == 1) {    
    WiFiClient wifiClient = server.available();   // listen for incoming clients
    if (wifiClient) {    
  
      // send a standard http response header
      wifiClient.println("HTTP/1.1 200 OK");
      wifiClient.println("Content-Type: text/html");
      wifiClient.println("Connection: close");
      wifiClient.println();
      wifiClient.println("<!DOCTYPE HTML><html><head><meta name=\"viewport\" content=\"width=device-width, initial-scale=1\">");
      wifiClient.println("<meta http-equiv=\"refresh\" content=\"30\"></head>");
      wifiClient.println("<body><div style=\"font-size: 3.5rem;\"><p></p><p>");
      wifiClient.println("<div>Temperatuur: ");
      wifiClient.println(getTemperature());
      wifiClient.println("°C</p></div><p>Luchtvochtigheid: ");
      wifiClient.println(getHumidity());
      wifiClient.println("%</p><p>Water: ");
      wifiClient.println(getWater());
      wifiClient.println("</p></div></div>");
      wifiClient.println(toJson());
      wifiClient.println("</body></html>");     
      // give the web browser time to receive the data
      delay(2);
  
      wifiClient.stop();                          // close the connection
    }
  } else {
    //esp_deep_sleep_enable_timer_wakeup(MQTT_INTERVAL * 1000000);    // Go to deepsleep if the Webserver is offline
    //esp_deep_sleep_start();
  }
}



// MQTT Connect
void mqttconnect() {
  while (!client.connected()) {                   // Try to connect to MQTT
    Serial.print("MQTT connecting...");
    if (client.connect(CLIENT)) {                 // Connect
      Serial.println("connected");
    } else {
      Serial.print("failed, status code =");
      Serial.print(client.state());
      Serial.println("try again in 5 seconds");
      delay(5000);                                // Wait 5 seconds before retrying
    }
  }




}

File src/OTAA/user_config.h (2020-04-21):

// -- Project -------------------------------------------
#define CLIENT                 "xxx"          // Client ID for the ESP

// -- Wifi ----------------------------------------------
#define WIFI_SSID              "xxx"             // [Ssid1] Wifi SSID
#define WIFI_PASS              "xxx"         // [Password1] Wifi password


// -- DHT - Sensor --------------------------------------
#define DHTTYPE                 DHT11                 // [Sensor] Change to DHT11, DHT21, DHT22
#define PIN_DHT                 22                    // [Sensor] Pin for DHT sensor

// -- Other - Sensor ------------------------------------
#define PIN_SOIL                32                    // [Sensor] Soil Sensor pin
#define PIN_LIGHT               33                    // [Sensor] Light Sensor pin
#define PIN_POWER               34                    // [Sensor] Power Sensor pin


// -- MQTT ----------------------------------------------
#define MQTT                    0                     // [MQTT] Mosquitto (0 = Off, 1 = Start)
#define MQTT_BROKER             "192.168.178.20"             // [MQTT] Set the IP adress from your MQ-Broker
#define MQTT_PORT               1883                  // [MQTT] MQTT Port on the Server
#define MQTT_TOPIC              "xxx"   // [MQTT] Set the topic for your queue
#define MQTT_INTERVAL           3600                  // [MQTT] Set the deepsleep time in seconds


// -- HTTP ---------------------------------------------- When webser is activ deepsleep will be disabled
#define WEB_SERVER              0                     // [WebServer] Web server (0 = Off, 1 = Start)
#define WEB_PORT                80                    // [WebServer] Port for web access


// not yet implemented. 
// -- Cayenne -------------------------------------------
//#define CAYENNE_SUPPORT         1                      // Cayenne support to 
//#define CAYENNE_PRINT Serial 
//#define SENSOR_PIN 5 // Do not use digital pins 0 or 1 since those conflict with the use of Serial.
//#define VIRTUAL_CHANNEL 1
//char username[] = "MQTT_USERNAME";
//char password[] = "MQTT_PASSWORD";
//char clientID[] = "CLIENT_ID";
